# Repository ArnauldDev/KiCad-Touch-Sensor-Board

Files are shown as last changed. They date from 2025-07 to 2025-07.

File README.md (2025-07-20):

# Proto Board Touch-Sensor Controller

Top view of the [board with 3D rendering](https://forum.kicad.info/t/simple-tutorial-how-to-create-blender-3d-model-from-kicad/46485) generated with [Blender](https://www.blender.org/), see [Import PCB 3D Models from KiCad](https://extensions.blender.org/add-ons/pcb3d-importer/):

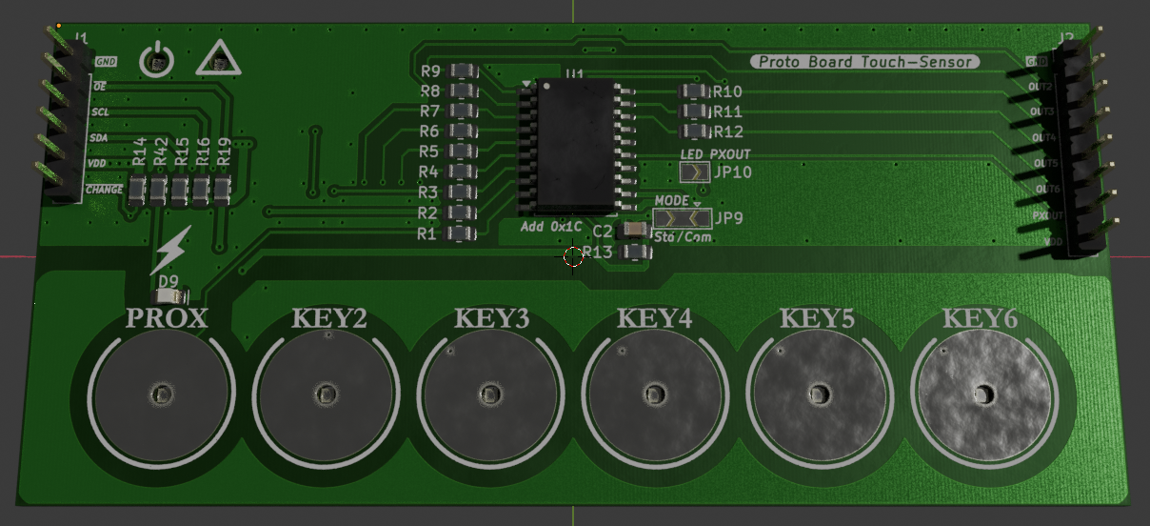
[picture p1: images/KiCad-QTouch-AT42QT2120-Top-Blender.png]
KiCad-QTouch-AT42QT2120-Top


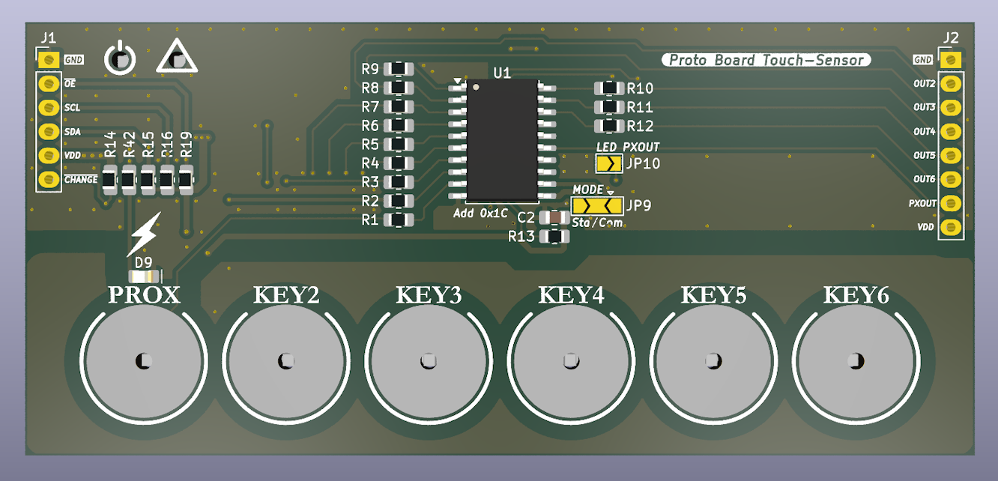
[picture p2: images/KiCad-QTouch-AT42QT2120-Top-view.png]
KiCad-QTouch-AT42QT2120-Top


Bottom view of the board and 3D rendering generated with Blender too:

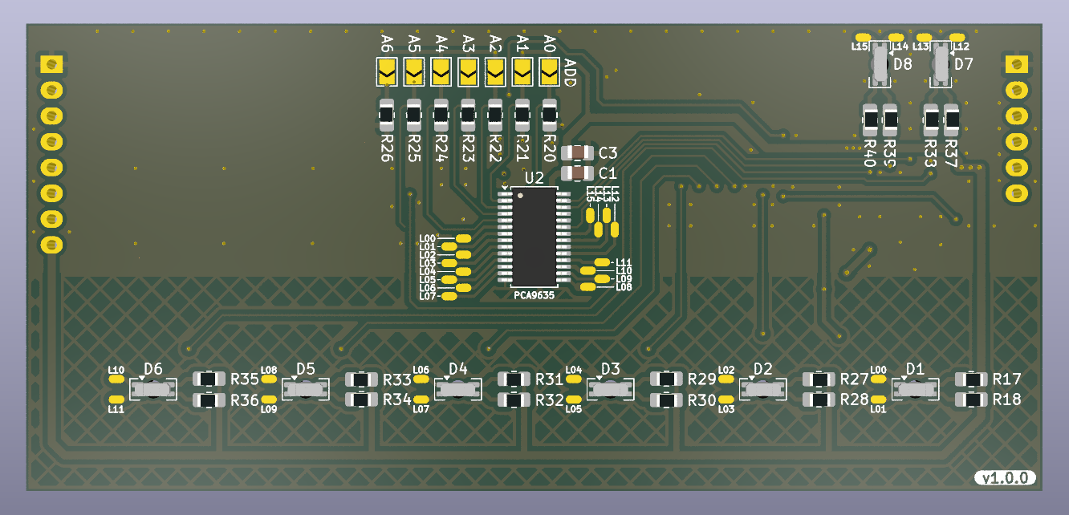
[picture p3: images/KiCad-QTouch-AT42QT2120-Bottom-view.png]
KiCad-QTouch-AT42QT2120-Bottom


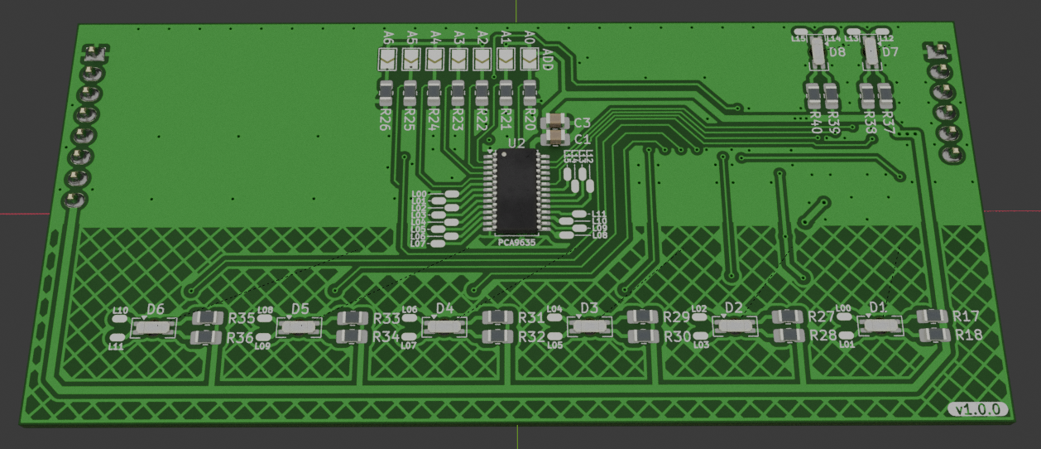
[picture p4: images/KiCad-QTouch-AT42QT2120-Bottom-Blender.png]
KiCad-QTouch-AT42QT2120-Bottom


## AT42QT2120

Touch Sensor QTouch [AT42QT2120](https://www.microchip.com/en-us/product/at42qt2120): [view pdf datasheet online](https://ww1.microchip.com/downloads/en/DeviceDoc/doc9634.pdf)

AT42QT2120 is a 10-channel capacitive touch sensor controller with I2C interface.

It is designed for applications such as buttons, sliders, and wheels.

AT42QT2120-SU = 20 pin 0.300 inch wide body SOIC package

[Hole for Backlighting LED - page 13](https://ww1.microchip.com/downloads/aemDocuments/documents/OTH/ApplicationNotes/ApplicationNotes/Atmel-42094-QTouch-Schematic-and-Layout-Checklist_ApplicationNote_AT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), see "Figure 3-2. Hole for Backlighting LED"

Example for [AT42QT_API](https://github.com/SmartTech/AT42QT/blob/master/AT42QT_API/QT2120.h)

## Demo board QT1 XPLAINED PRO EXTENSION KIT

Part Number: [ATQT1-XPRO](https://www.microchip.com/en-us/development-tool/ATQT1-XPRO)

[SAM D20 XPLAINED PRO EVALUATION KIT](https://ww1.microchip.com/downloads/aemDocuments/documents/OTH/ProductDocuments/UserGuides/Atmel-42102-SAMD20-Xplained-Pro_User-Guide.pdf)<br>
Part Number: [ATSAMD20-XPRO](https://www.microchip.com/en-us/development-tool/ATSAMD20-XPRO)

---

<br />

## SMD LED reverse mount

LED, Rouge, Vert jaune, CMS - Montage inversé, Rectangulaire, R 20mA, YG 20mA<br>
* [Farnell 2908898](https://fr.farnell.com/rohm/sml-822mv8wt86/led-rouge-jaune-vert-30-25mcd/dp/2908898)
* [Rohm Datasheet](https://fscdn.rohm.com/en/products/databook/datasheet/opto/led/chip_multi/sml-822mv8wt86-e.pdf)

| Package view | Reverse mount available, 2-color LED (Yellow-green/Red) |
| :---: | :--- |
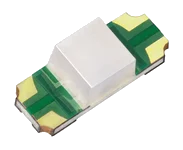
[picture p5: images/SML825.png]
|  | Part Number: [SML-822MV8WT86](https://www.rohm.com/products/led/chip-leds-multi-color-type/sml-822mv8w-product)<br>SML-82 series is a two-color LED chip LED for back-mounting.<br>Rear mounting enables single-sided mounting, contributing to space saving in the mounting area. |

---

## Driver de LED DC/DC

### PCA9635PW,118

LED-Driver-PCA9635

> Code Commande Farnell : [1854073](https://fr.farnell.com/nxp/pca9635pw-118/driver-de-led-rgba-28-tssop/dp/1854073)
> Quantité 1, Prix (TVA incluse) 2,760€
> Driver LED, Bus I2C, Isolé, 16 bits, 1MHz, Sortie 5,5V/25mA, Entrée 2,3V à 5,5V
> https://fr.aliexpress.com/item/33038992925.html
> https://www.nxp.com/docs/en/data-sheet/PCA9635.pdf

[Breakout PCA9685PW module Servomotor Shield on Aliexpress](https://fr.aliexpress.com/item/1005007462728654.html)

<!-- ![aliexpress-module-servo-shield](images/aliexpress-module-servo-shield.png) -->

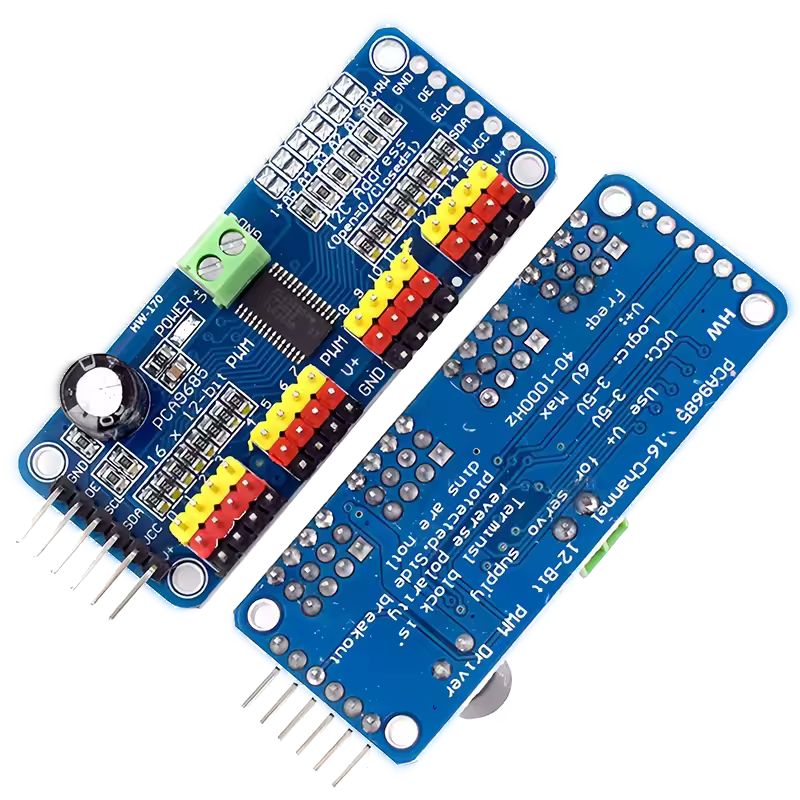
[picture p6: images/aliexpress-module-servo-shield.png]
aliexpress-module-servo-shield


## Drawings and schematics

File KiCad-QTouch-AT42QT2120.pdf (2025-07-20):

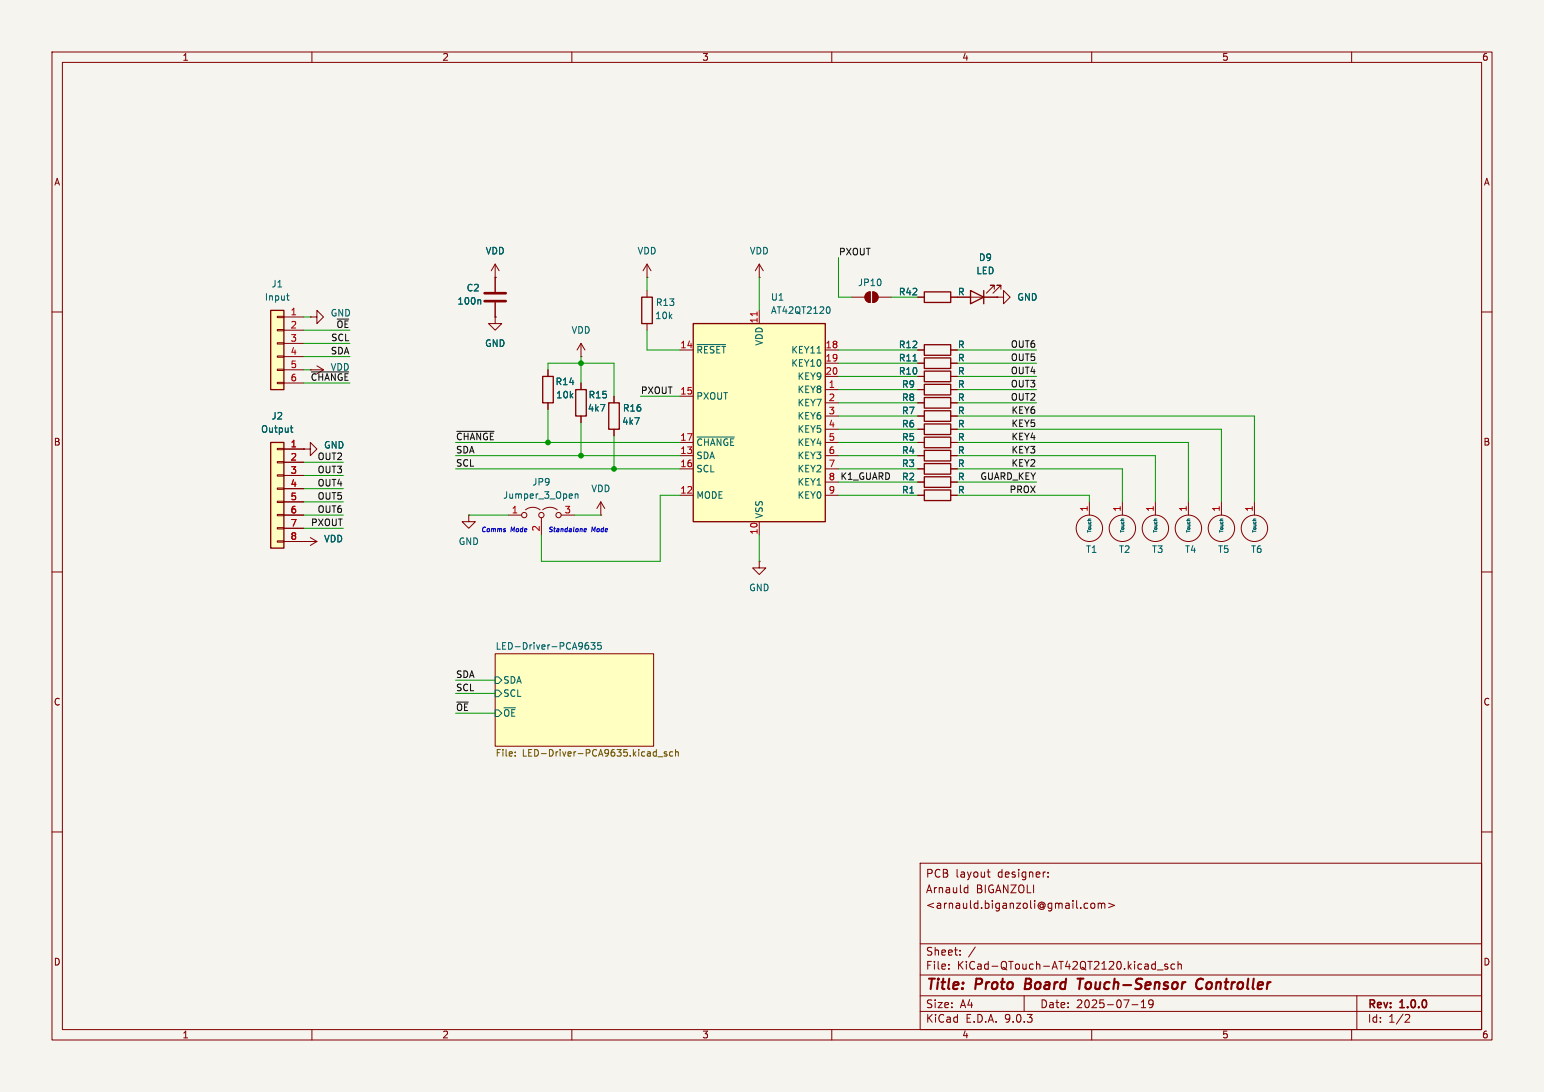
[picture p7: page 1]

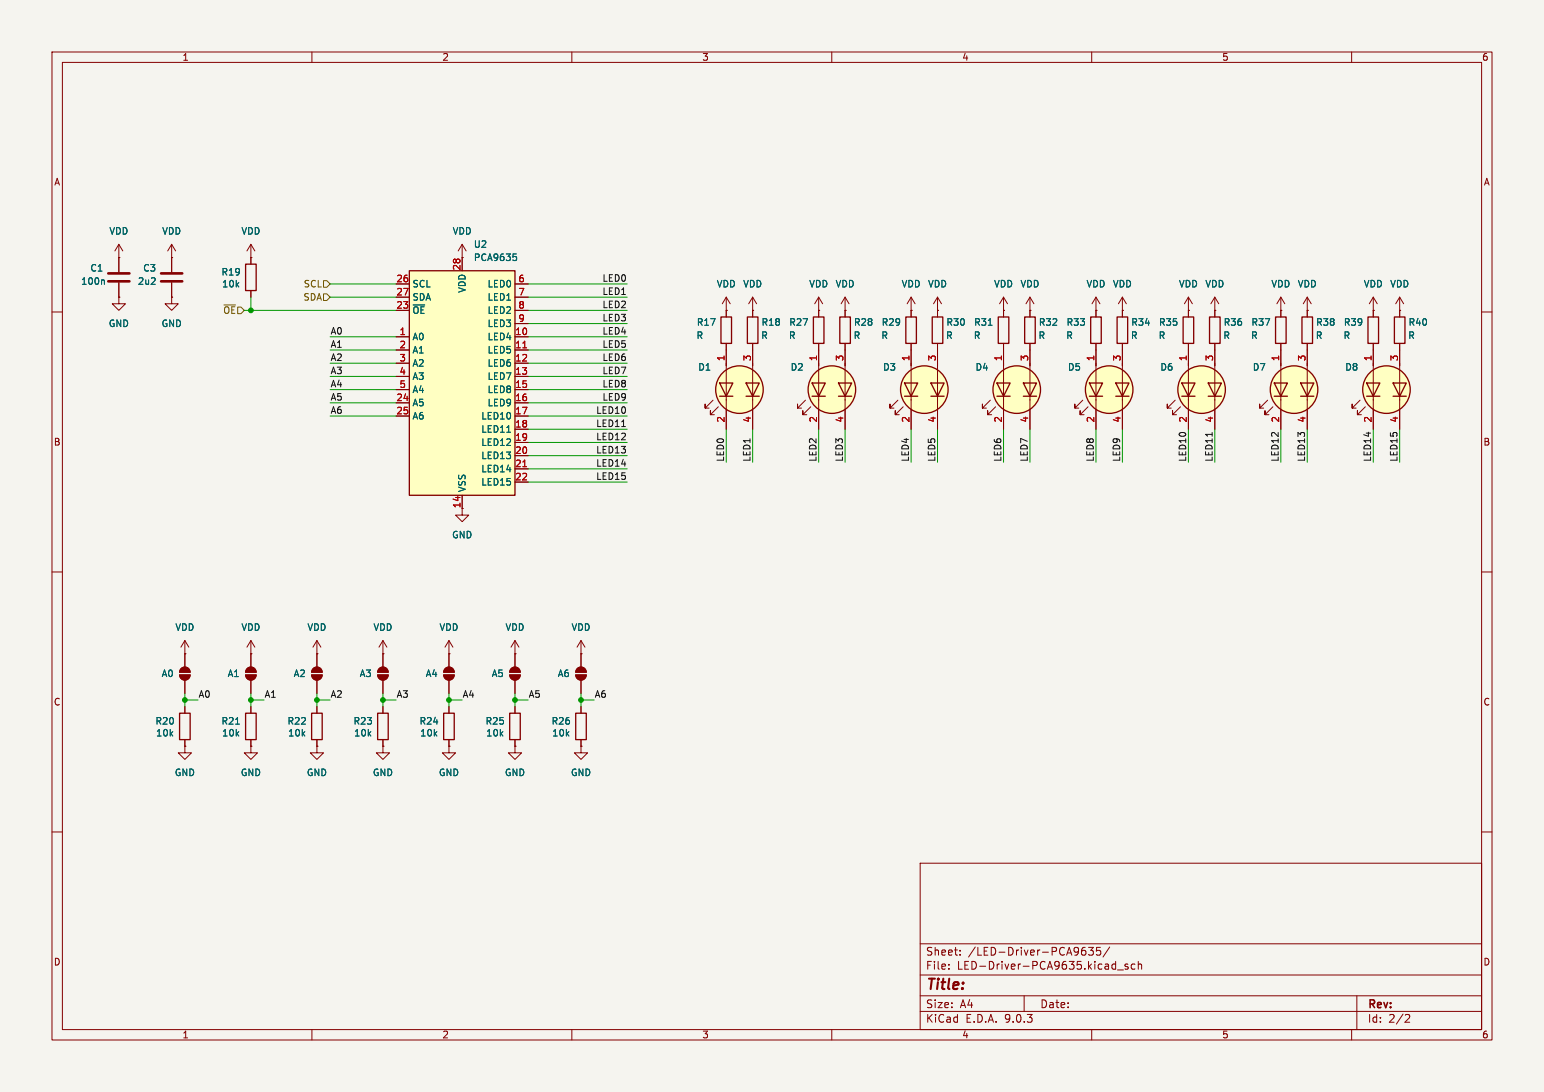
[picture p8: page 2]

Id: 2/2 Title: File: LED-Driver-PCA9635.kicad_sch Sheet: /LED-Driver-PCA9635/

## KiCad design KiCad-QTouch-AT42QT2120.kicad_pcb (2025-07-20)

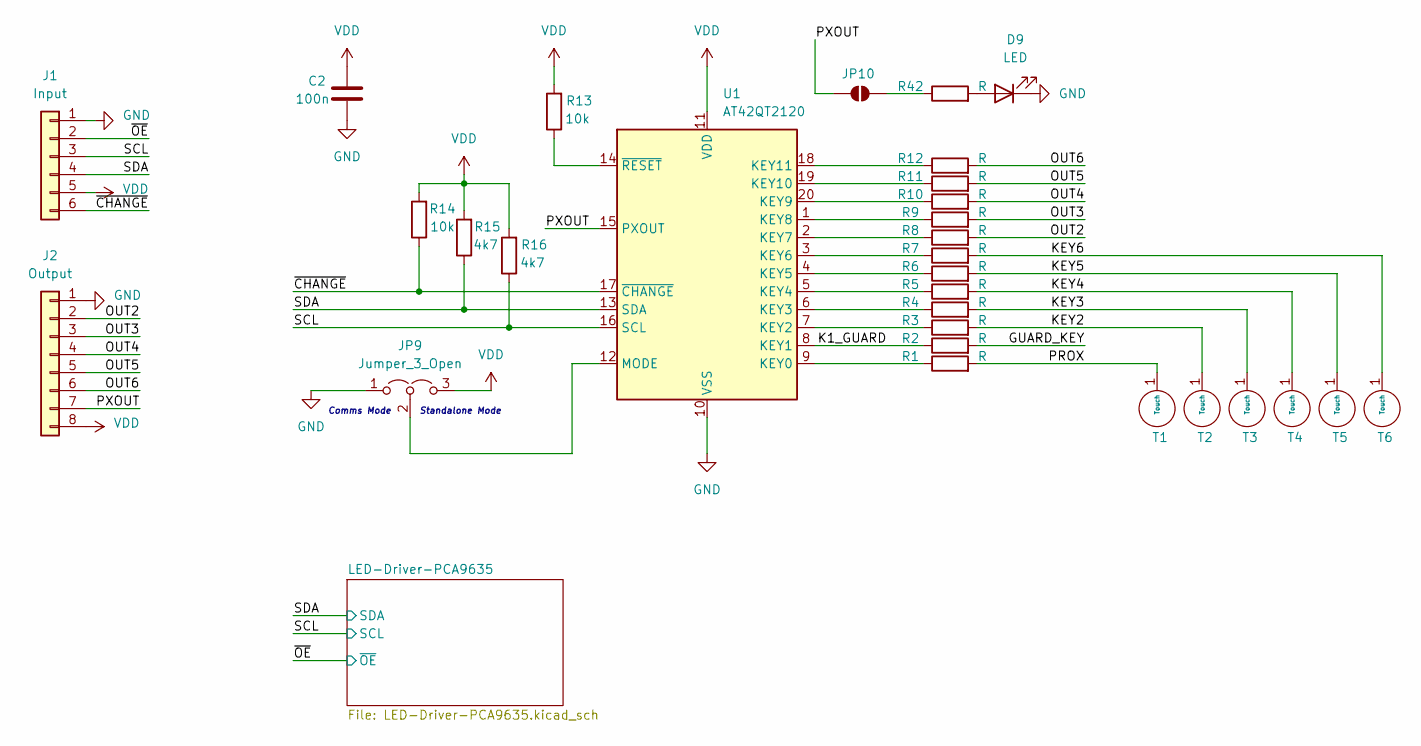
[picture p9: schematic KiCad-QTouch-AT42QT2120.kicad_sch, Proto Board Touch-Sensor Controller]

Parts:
C2: 100n; C_0805_2012Metric_Pad1.18x1.45mm_HandSolder
D9: LED; LED_0805_2012Metric_Pad1.15x1.40mm_HandSolder
J1: Input; PinHeader_1x06_P2.54mm_Vertical
J2: Output; PinHeader_1x08_P2.54mm_Vertical
JP9: Jumper_3_Open; SolderJumper-3_P2.0mm_Open_TrianglePad1.0x1.5mm
JP10: SolderJumper_2_Open; SolderJumper-2_P1.3mm_Open_TrianglePad1.0x1.5mm
R1, R2, R3, R4, R5, R6, R7, R8, R9, R10, R11, R12, R42: R; R_0805_2012Metric_Pad1.20x1.40mm_HandSolder
R13, R14: 10k; R_0805_2012Metric_Pad1.20x1.40mm_HandSolder
R15, R16: 4k7; R_0805_2012Metric_Pad1.20x1.40mm_HandSolder
T1, T2, T3, T4, T5, T6: Touch_12mm_round
U1: AT42QT2120; SOIC-20W_7.5x12.8mm_P1.27mm

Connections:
/GUARD_KEY: R2.2
/K1_GUARD: R2.1, U1.8 (KEY1)
/KEY2: R3.2, T2.1 (Touch)
/KEY3: R4.2, T3.1 (Touch)
/KEY4: R5.2, T4.1 (Touch)
/KEY5: R6.2, T5.1 (Touch)
/KEY6: R7.2, T6.1 (Touch)
/OUT2: J2.2, R8.2
/OUT3: J2.3, R9.2
/OUT4: J2.4, R10.2
/OUT5: J2.5, R11.2
/OUT6: J2.6, R12.2
/PROX: R1.2, T1.1 (Touch)
/PXOUT: J2.7, JP10.1 (A), U1.15 (PXOUT)
/SCL: J1.3, R16.1, U1.16 (SCL); also elsewhere on the board
/SDA: J1.4, R15.1, U1.13 (SDA); also elsewhere on the board
/~CHANGE: J1.6, R14.1, U1.17 (~CHANGE)
/~OE: J1.2; also elsewhere on the board
GND: C2.2, D9.1 (K), J1.1, J2.1, JP9.1 (A), U1.10 (VSS); also elsewhere on the board
unnamed: D9.2 (A), R42.2
unnamed: JP9.2 (C), U1.12 (MODE)
unnamed: JP10.2 (B), R42.1
unnamed: R1.1, U1.9 (KEY0)
unnamed: R3.1, U1.7 (KEY2)
unnamed: R4.1, U1.6 (KEY3)
unnamed: R5.1, U1.5 (KEY4)
unnamed: R6.1, U1.4 (KEY5)
unnamed: R7.1, U1.3 (KEY6)
unnamed: R8.1, U1.2 (KEY7)
unnamed: R9.1, U1.1 (KEY8)
unnamed: R10.1, U1.20 (KEY9)
unnamed: R11.1, U1.19 (KEY10)
unnamed: R12.1, U1.18 (KEY11)
unnamed: R13.1, U1.14 (~RESET)
VDD: C2.1, J1.5, J2.8, JP9.3 (B), R13.2, R14.2, R15.2, R16.2, U1.11 (VDD); also elsewhere on the board

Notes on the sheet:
Standalone Mode
Comms Mode

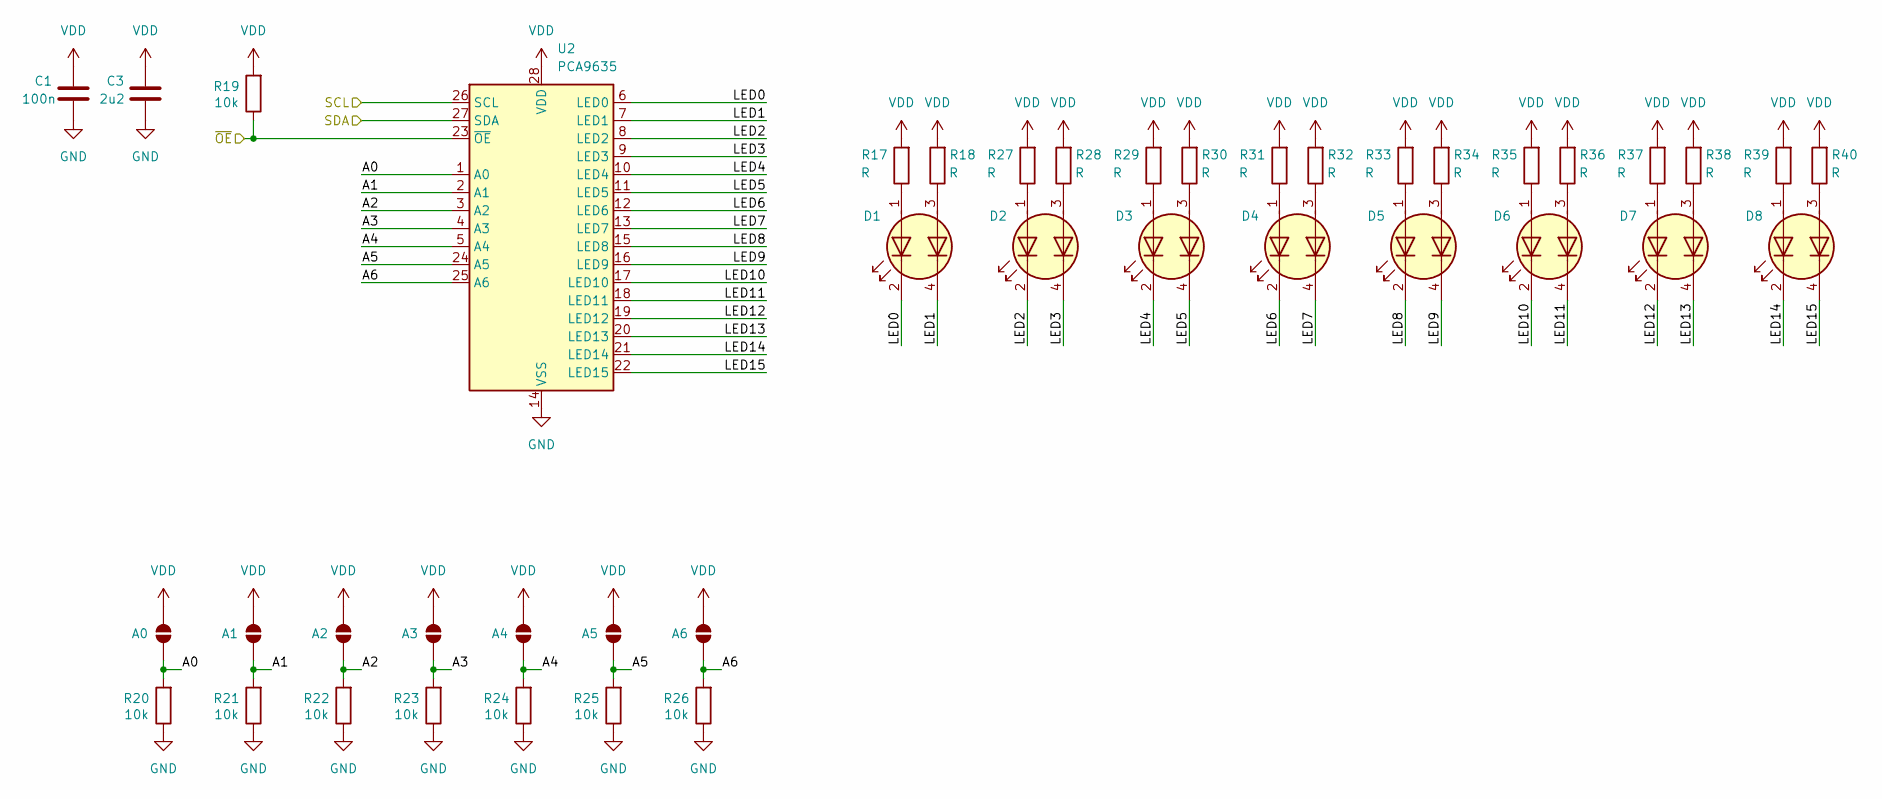
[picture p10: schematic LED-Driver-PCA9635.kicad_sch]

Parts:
A0, A1, A2, A3, A4, A5, A6: SolderJumper_2_Open; SolderJumper-2_P1.3mm_Open_TrianglePad1.0x1.5mm
C1: 100n; C_0805_2012Metric_Pad1.18x1.45mm_HandSolder
C3: 2u2; C_0805_2012Metric_Pad1.18x1.45mm_HandSolder
D1, D2, D3, D4, D5, D6, D7, D8: LED_Dual_AKAK; LED_SML-822MV8WT86
R17, R18, R27, R28, R29, R30, R31, R32, R33, R34, R35, R36, R37, R38, R39, R40: R; R_0805_2012Metric_Pad1.20x1.40mm_HandSolder
R19, R20, R21, R22, R23, R24, R25, R26: 10k; R_0805_2012Metric_Pad1.20x1.40mm_HandSolder
U2: PCA9635; TSSOP-28_4.4x9.7mm_P0.65mm

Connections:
/LED-Driver-PCA9635/A0: A0.2 (B), R20.2, U2.1 (A0)
/LED-Driver-PCA9635/A1: A1.2 (B), R21.2, U2.2 (A1)
/LED-Driver-PCA9635/A2: A2.2 (B), R22.2, U2.3 (A2)
/LED-Driver-PCA9635/A3: A3.2 (B), R23.2, U2.4 (A3)
/LED-Driver-PCA9635/A4: A4.2 (B), R24.2, U2.5 (A4)
/LED-Driver-PCA9635/A5: A5.2 (B), R25.2, U2.24 (A5)
/LED-Driver-PCA9635/A6: A6.2 (B), R26.2, U2.25 (A6)
/LED-Driver-PCA9635/LED0: D1.2 (K1), U2.6 (LED0)
/LED-Driver-PCA9635/LED1: D1.4 (K2), U2.7 (LED1)
/LED-Driver-PCA9635/LED2: D2.2 (K1), U2.8 (LED2)
/LED-Driver-PCA9635/LED3: D2.4 (K2), U2.9 (LED3)
/LED-Driver-PCA9635/LED4: D3.2 (K1), U2.10 (LED4)
/LED-Driver-PCA9635/LED5: D3.4 (K2), U2.11 (LED5)
/LED-Driver-PCA9635/LED6: D4.2 (K1), U2.12 (LED6)
/LED-Driver-PCA9635/LED7: D4.4 (K2), U2.13 (LED7)
/LED-Driver-PCA9635/LED8: D5.2 (K1), U2.15 (LED8)
/LED-Driver-PCA9635/LED9: D5.4 (K2), U2.16 (LED9)
/LED-Driver-PCA9635/LED10: D6.2 (K1), U2.17 (LED10)
/LED-Driver-PCA9635/LED11: D6.4 (K2), U2.18 (LED11)
/LED-Driver-PCA9635/LED12: D7.2 (K1), U2.19 (LED12)
/LED-Driver-PCA9635/LED13: D7.4 (K2), U2.20 (LED13)
/LED-Driver-PCA9635/LED14: D8.2 (K1), U2.21 (LED14)
/LED-Driver-PCA9635/LED15: D8.4 (K2), U2.22 (LED15)
/SCL: U2.26 (SCL); also elsewhere on the board
/SDA: U2.27 (SDA); also elsewhere on the board
/~OE: R19.1, U2.23 (~OE); also elsewhere on the board
GND: C1.2, C3.2, R20.1, R21.1, R22.1, R23.1, R24.1, R25.1, R26.1, U2.14 (VSS); also elsewhere on the board
unnamed: D1.1 (A1), R17.1
unnamed: D1.3 (A2), R18.1
unnamed: D2.1 (A1), R27.1
unnamed: D2.3 (A2), R28.1
unnamed: D3.1 (A1), R29.1
unnamed: D3.3 (A2), R30.1
unnamed: D4.1 (A1), R31.1
unnamed: D4.3 (A2), R32.1
unnamed: D5.1 (A1), R33.1
unnamed: D5.3 (A2), R34.1
unnamed: D6.1 (A1), R35.1
unnamed: D6.3 (A2), R36.1
unnamed: D7.1 (A1), R37.1
unnamed: D7.3 (A2), R38.1
unnamed: D8.1 (A1), R39.1
unnamed: D8.3 (A2), R40.1
VDD: A0.1 (A), A1.1 (A), A2.1 (A), A3.1 (A), A4.1 (A), A5.1 (A), A6.1 (A), C1.1, C3.1, R17.2, R18.2, R19.2, R27.2, R28.2, R29.2, R30.2, R31.2, R32.2, R33.2, R34.2, R35.2, R36.2, R37.2, R38.2, R39.2, R40.2, U2.28 (VDD); also elsewhere on the board

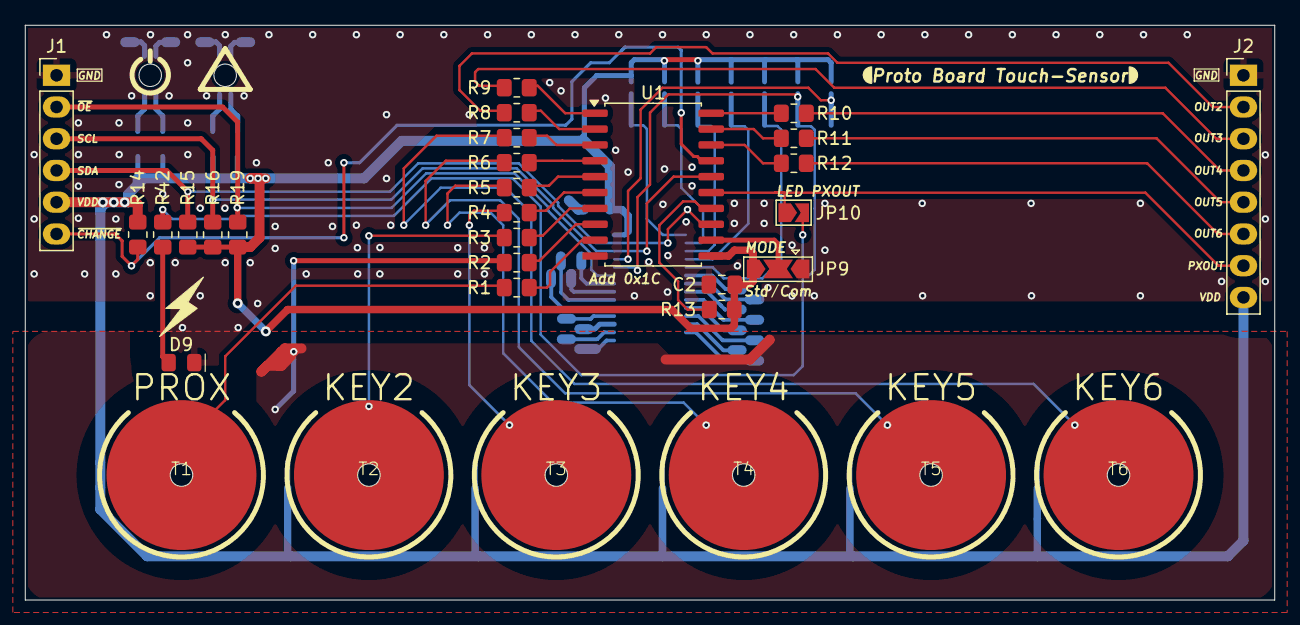
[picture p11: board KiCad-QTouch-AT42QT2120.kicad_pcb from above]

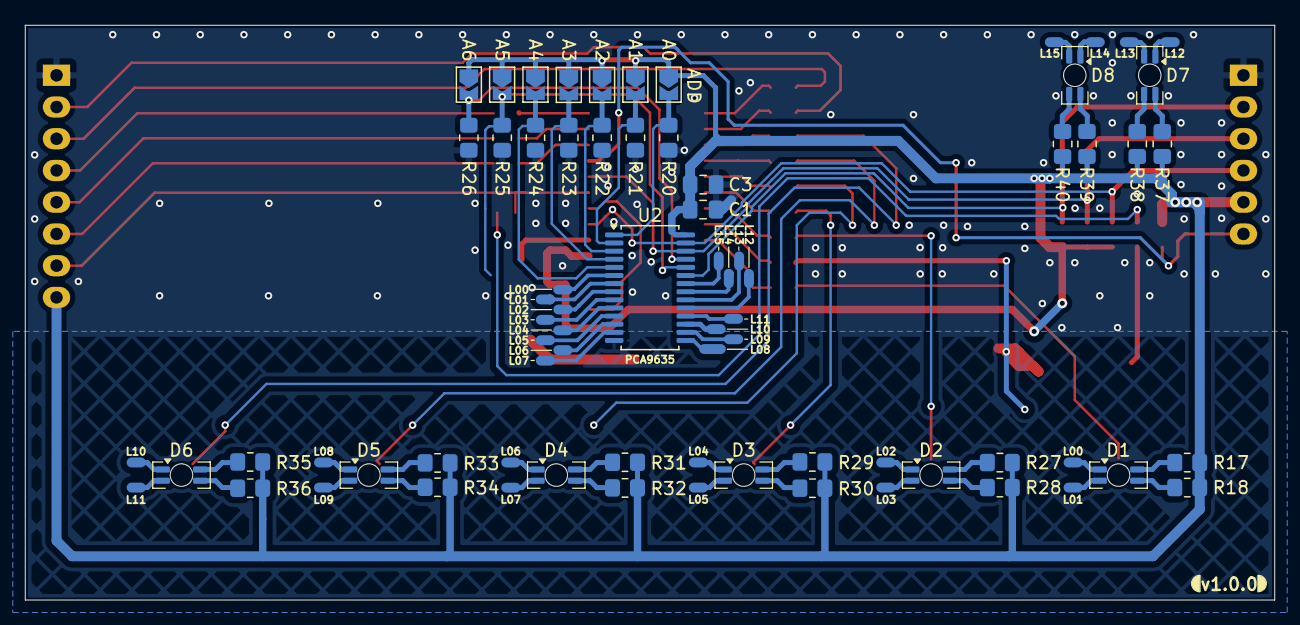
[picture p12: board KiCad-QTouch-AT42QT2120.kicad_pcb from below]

Board: 2 copper layers, 100.0 x 46.0 mm, 72 parts (41 on the bottom side), 73 nets.

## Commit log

2025-07-20 KiCad project partage
    [KiCad-QTouch-AT42QT2120.kicad_pcb, KiCad-QTouch-AT42QT2120.kicad_sch, LED-Driver-PCA9635.kicad_sch]
2025-07-20 3D rendering generation with blender
    [KiCad-QTouch-AT42QT2120.kicad_pcb, KiCad-QTouch-AT42QT2120.kicad_sch]
2025-07-20 Add reverse mount LED
